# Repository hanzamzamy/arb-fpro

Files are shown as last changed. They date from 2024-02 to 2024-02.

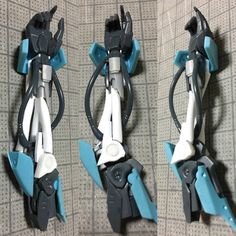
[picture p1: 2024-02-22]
Mechanical/Macrobot_Silvia Nur Aziza_Mechanical/07cd2b10f6570b833456bf622130a239.jpg

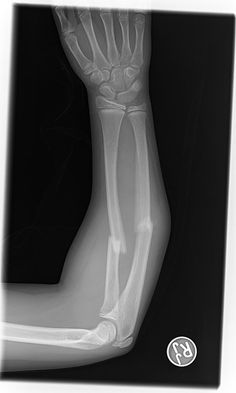
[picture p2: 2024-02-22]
Mechanical/Macrobot_Silvia Nur Aziza_Mechanical/10383fedec357cac335563712656db4f.jpg

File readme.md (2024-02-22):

# ARb Project
## Introduction
ARb is a robotic arm with 4 degrees of freedom. It is designed to be used in a variety of applications, including pick and place, etc. The arm is controlled by a host computer, which communicates with an STM32 to control the servos using UART via USB. The arm is also equipped with a sensor and a gripper, which can be used to pick up and manipulate objects. The arm is designed to be easy to use. The arm also designed to be affordable, with a total cost of less than Rp500.000,00. _Although we spent more because of trial and error, and we also bought some parts in a higher price than the market price._
## Features
- 4 degrees of freedom
- 1 gripper with integrated sensor
- Automatic find and pick up object
- Easy to use
- Fully programmable
## Components
- 3x MG996R Servo
- 2x MG90S Servo
- 1x VL53L0X Sensor
- 1x STM32F401CCU6
- 1x LM2596 DC-DC Step Down
- Custom PCB and Acrylic parts
## Tech Stack
- C -> STM32
    - HAL -> Hardware Abstraction Layer
    - VL53L0X -> Sensor
    - USB CDC -> Communication
- Python -> Host Computer
  - PySerial -> Communication
  - IKPy -> Inverse Kinematics
- Solidworks -> Design
- KiCad -> PCB Design
## Expenditure
[Rincian_Anggaran.pdf](https://github.com/hanzamzamy/arb-fpro/blob/master/Rincian_Anggaran.pdf)
## Documentation
[Video Demo.mp4](https://github.com/hanzamzamy/arb-fpro/blob/master/Dokumentasi/Video%20Demo.mp4)
[Robot.jpg](https://github.com/hanzamzamy/arb-fpro/blob/master/Dokumentasi/Barang%20e.jpg)
[Photo1.jpg](https://github.com/hanzamzamy/arb-fpro/blob/master/Dokumentasi/1.jpg)
[Photo2.jpg](https://github.com/hanzamzamy/arb-fpro/blob/master/Dokumentasi/1.jpg)
## Team
- Mechanical - [Silvia Nur Aziza]()
- Electrical - [Rayhan Rizqi Zamzamy](https://github.com/hanzamzamy)
- Programming - [Nabiel Nizar Anwari](https://github.com/bielnzar)

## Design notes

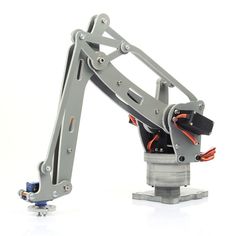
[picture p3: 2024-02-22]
Mechanical/Macrobot_Silvia Nur Aziza_Mechanical/8682ff16a06bd647c6e8e3005136eaa1.jpg

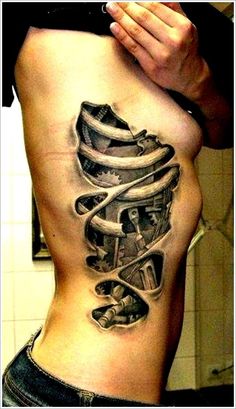
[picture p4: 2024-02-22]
Mechanical/Macrobot_Silvia Nur Aziza_Mechanical/3cdeb58c5378929b38347c03fc18d9f9.jpg

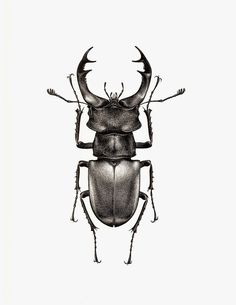
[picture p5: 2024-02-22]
Mechanical/Macrobot_Silvia Nur Aziza_Mechanical/ec5d5dfce41e124278e7852ab5f933ce.jpg

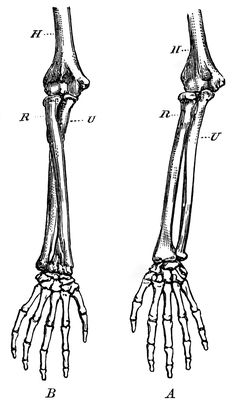
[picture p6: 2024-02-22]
Mechanical/Macrobot_Silvia Nur Aziza_Mechanical/0e78239ebd3d4895ee9c12c9efb630f2.jpg

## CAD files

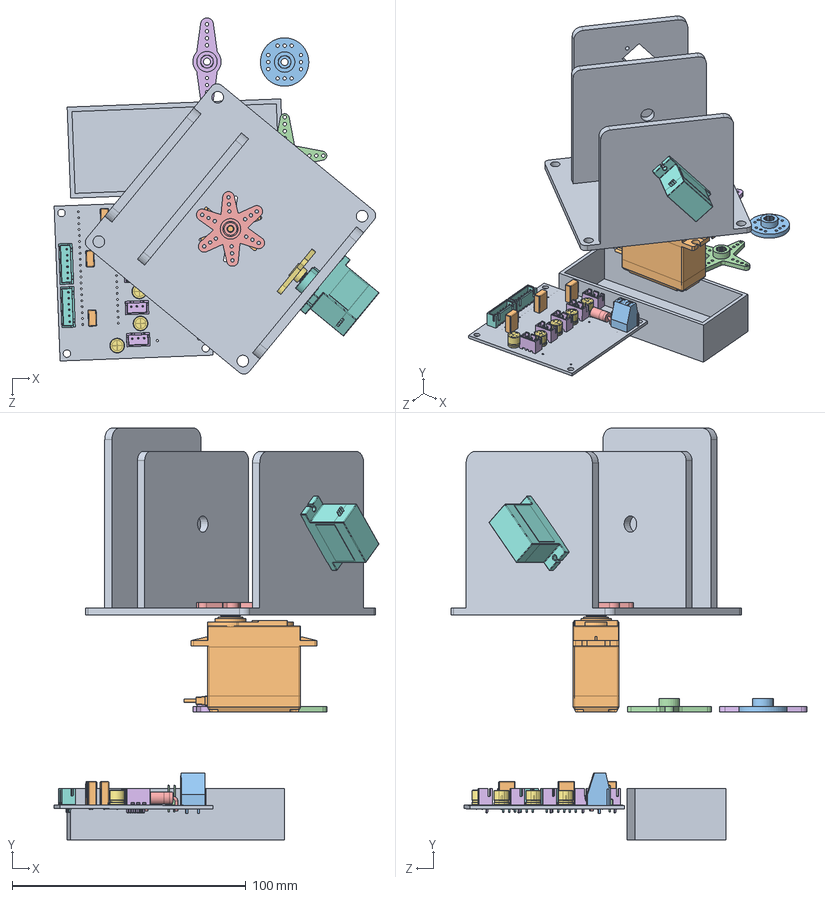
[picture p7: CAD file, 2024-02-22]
Mechanical/Macrobot_Silvia Nur Aziza_Mechanical/BASE PCB.SLDASM
138.9 x 176.2 x 152.4 mm
Robot base
servoMotorMG996R
attachmentStar
MG90servo_gear
Servo-MG90S.step
baterai
SOLID.step x 3
SOLID-0.step
SOLID-1.step
SOLID-2.step
SOLID-3.step x 5
SOLID-4.step x 5
SOLID-5.step x 2
FP_Abinara PCB.step

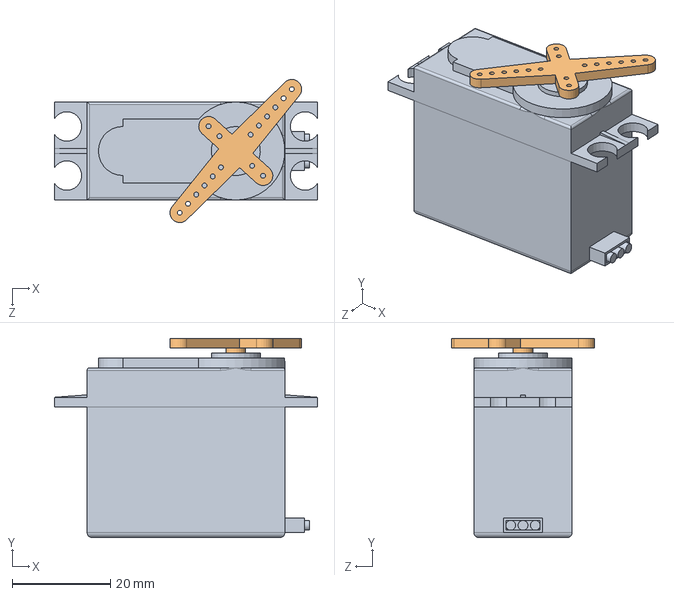
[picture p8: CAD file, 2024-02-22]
Mechanical/Macrobot_Silvia Nur Aziza_Mechanical/mg996-servo-motor-180-1.snapshot.1/Servo MG995 180/Servo MG995 Assembly.SLDASM
53.6 x 40.6 x 29.2 mm
Servo MG995
servo axe

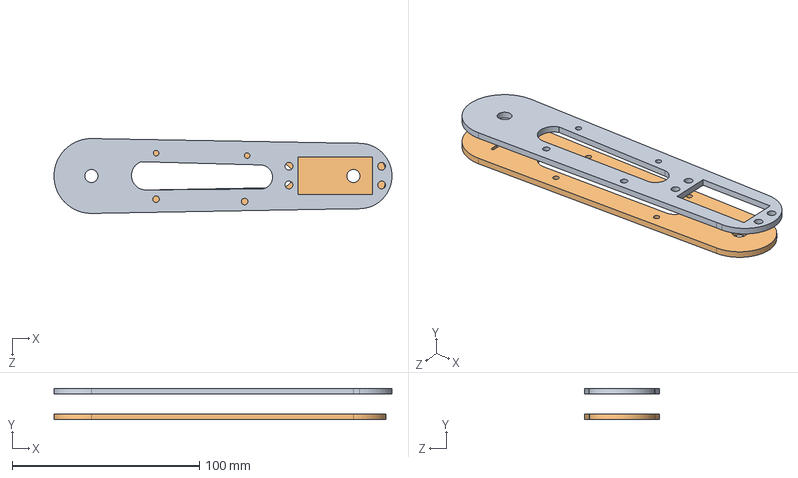
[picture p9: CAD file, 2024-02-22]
Mechanical/Macrobot_Silvia Nur Aziza_Mechanical/refisni/Assem1.SLDASM
180.6 x 16.8 x 40.0 mm
atas kanan - Copy
bawah - Copy

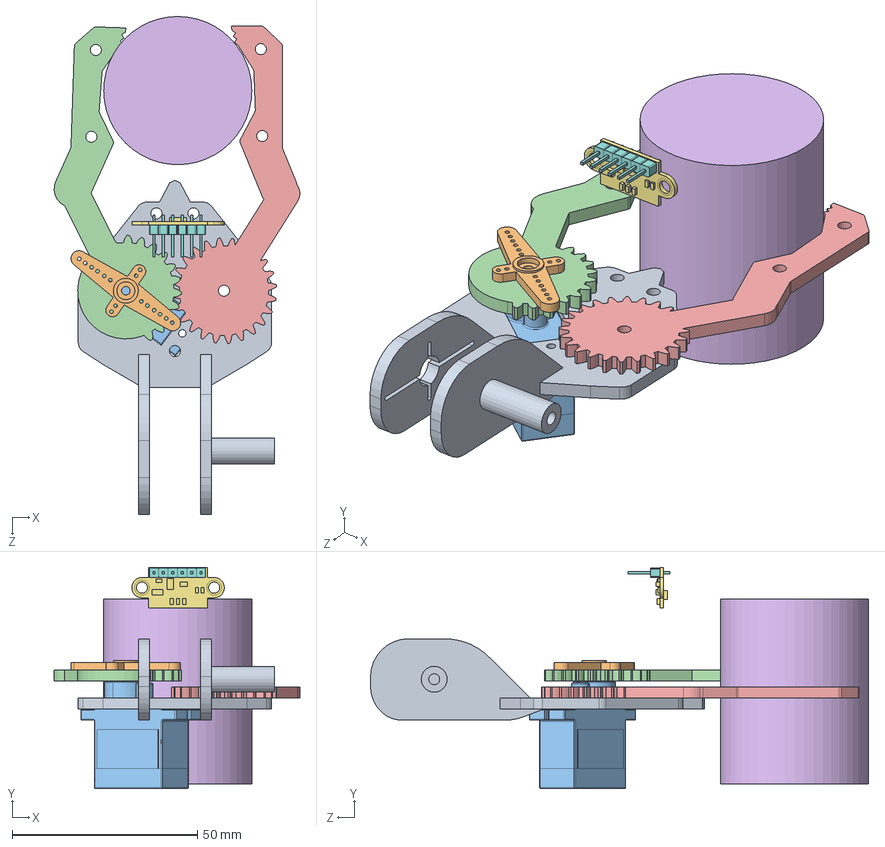
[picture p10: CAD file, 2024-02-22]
Mechanical/Macrobot_Silvia Nur Aziza_Mechanical/gripperr tolong fiksss.SLDASM
66.3 x 59.8 x 134.5 mm
tatakan griper bawah - Copy
MG90servo_gear
Gripper - Copy
capitt kanan fikss
siliner
vl53l0x_PCB.STEP
pin_header.STEP x 6

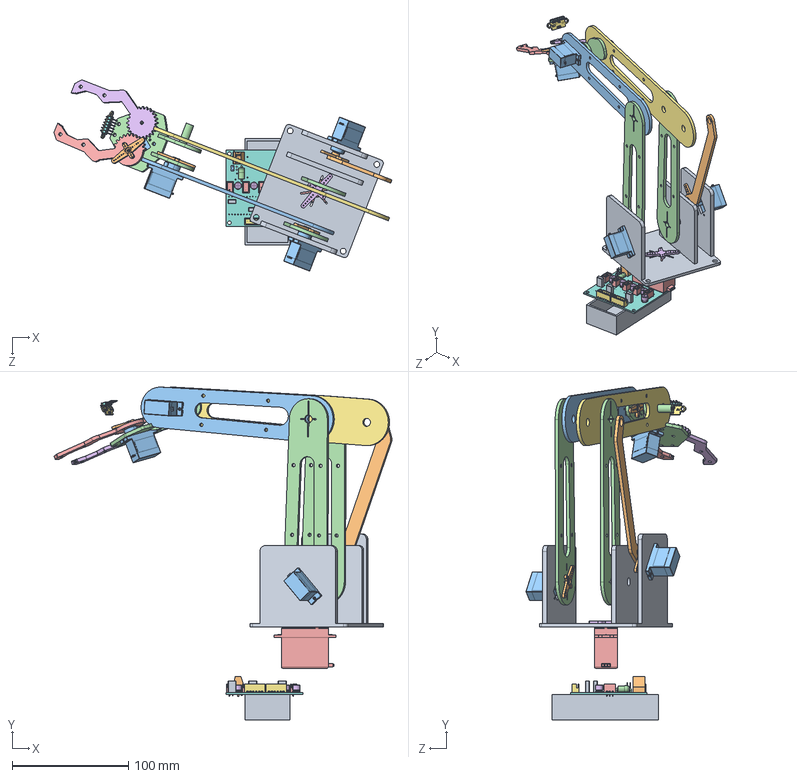
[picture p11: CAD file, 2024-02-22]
Mechanical/Macrobot_Silvia Nur Aziza_Mechanical/0totalll.SLDASM
290.9 x 286.3 x 164.5 mm
Robot base
MG90servo_gear x 4
Servo-MG90S.step x 4
tatakan griper bawah - Copy
Gripper - Copy
capitt kanan fikss
vl53l0x_PCB.STEP
pin_header.STEP x 6
SOLID.step x 3
SOLID-0.step
SOLID-1.step
SOLID-2.step
SOLID-3.step x 5
SOLID-4.step x 5
SOLID-5.step x 2
FP_Abinara PCB.step
baterai
penggerak
0atas kanan
0bawah x 2
Servo MG995
servo axe
0atas kiri pjg

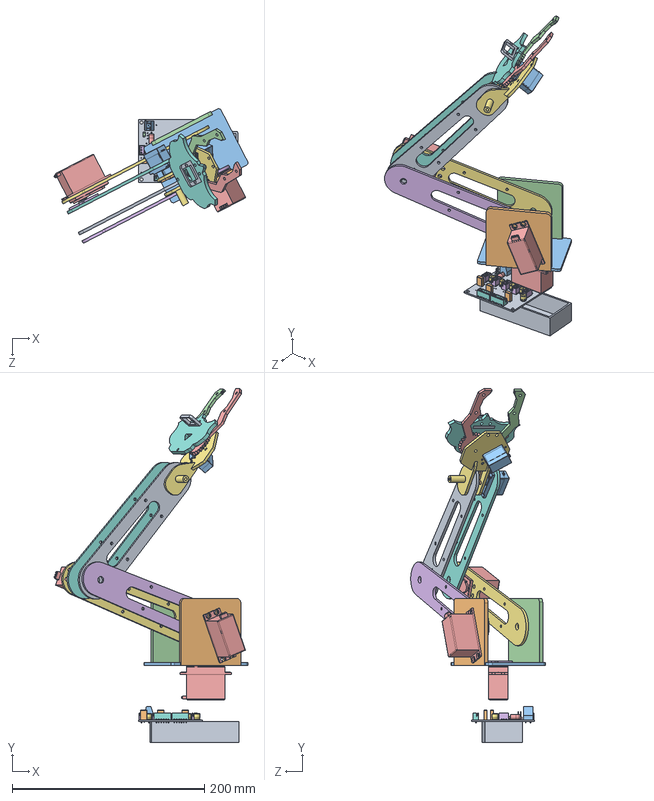
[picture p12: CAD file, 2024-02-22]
Mechanical/Macrobot_Silvia Nur Aziza_Mechanical/00total akh.SLDASM
201.8 x 368.3 x 140.1 mm
baterai
SOLID.step x 3
SOLID-0.step
SOLID-1.step
SOLID-2.step
SOLID-3.step x 5
SOLID-4.step x 5
SOLID-5.step x 2
FP_Abinara PCB.step
db 2 - Copy
revisi base
db 1
Servo MG995 x 3
servo axe x 3
tatakan griper bawah - Copy
kepala bolong
monting
MG90servo_gear x 2
Servo-MG90S.step x 2
Gripper - Copy
griper kanan fiks
bawah - Copy
atas kanan - Copy
0atas kanan
0bawah

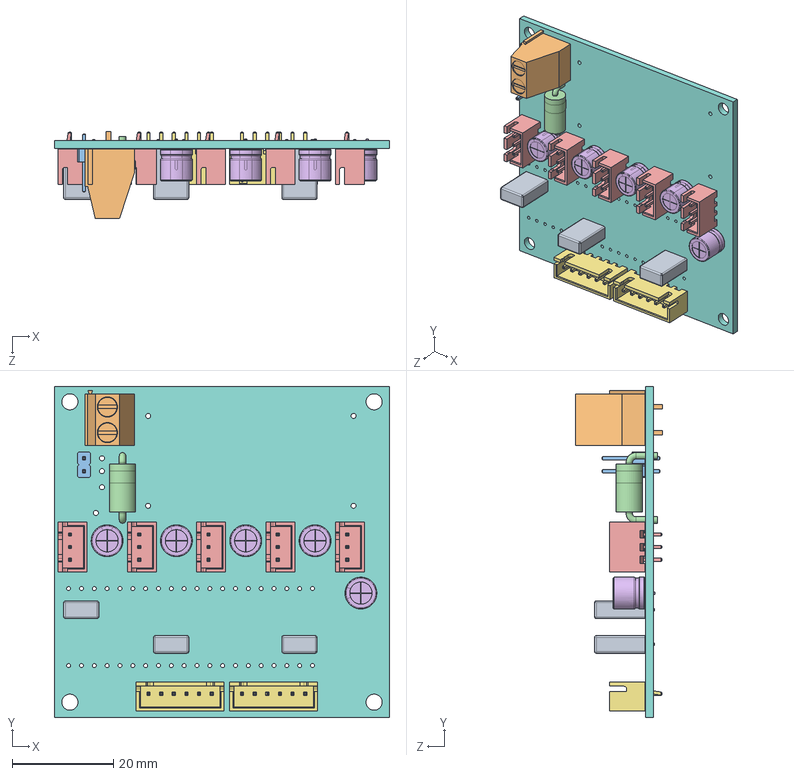
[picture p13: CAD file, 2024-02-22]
Mechanical/Macrobot_Silvia Nur Aziza_Mechanical/FP_Abinara.SLDASM
66.3 x 65.5 x 17.3 mm
SOLID.step x 3
SOLID-0.step
SOLID-1.step
SOLID-2.step
SOLID-3.step x 5
SOLID-4.step x 5
SOLID-5.step x 2
FP_Abinara PCB.step

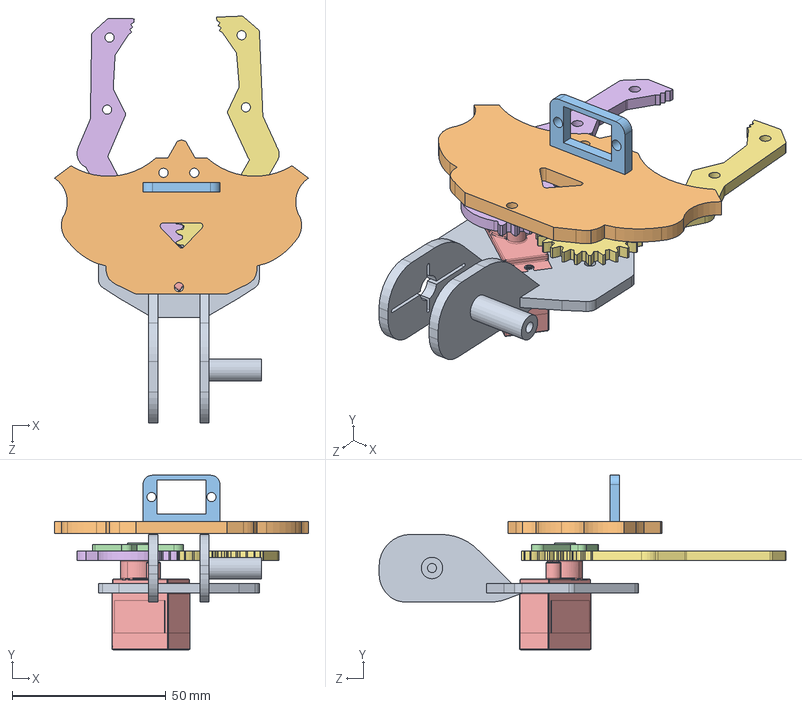
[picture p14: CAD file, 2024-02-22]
Mechanical/Macrobot_Silvia Nur Aziza_Mechanical/gfdgf.SLDASM
82.6 x 56.7 x 132.2 mm
tatakan griper bawah - Copy
kepala bolong
monting
MG90servo_gear
Servo-MG90S.step
Gripper - Copy
griper kanan fiks

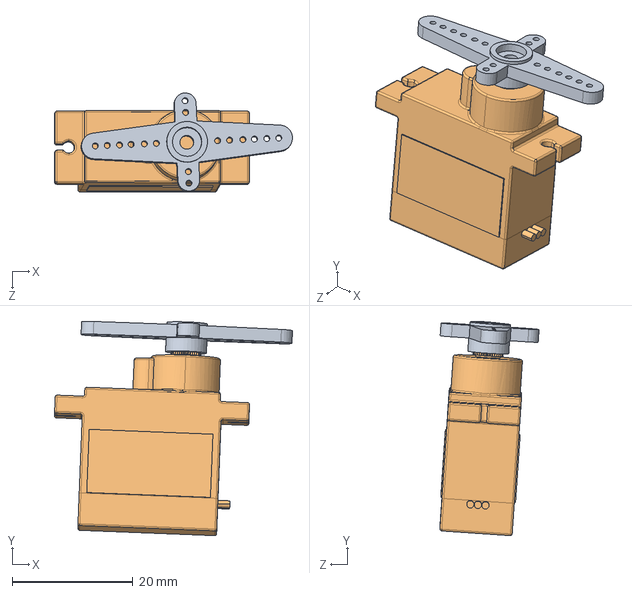
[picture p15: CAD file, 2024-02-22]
Mechanical/Macrobot_Silvia Nur Aziza_Mechanical/MG90S DENGAN BALING BALINGGG.SLDASM
39.4 x 35.5 x 16.4 mm
MG90servo_gear
Servo-MG90S.step

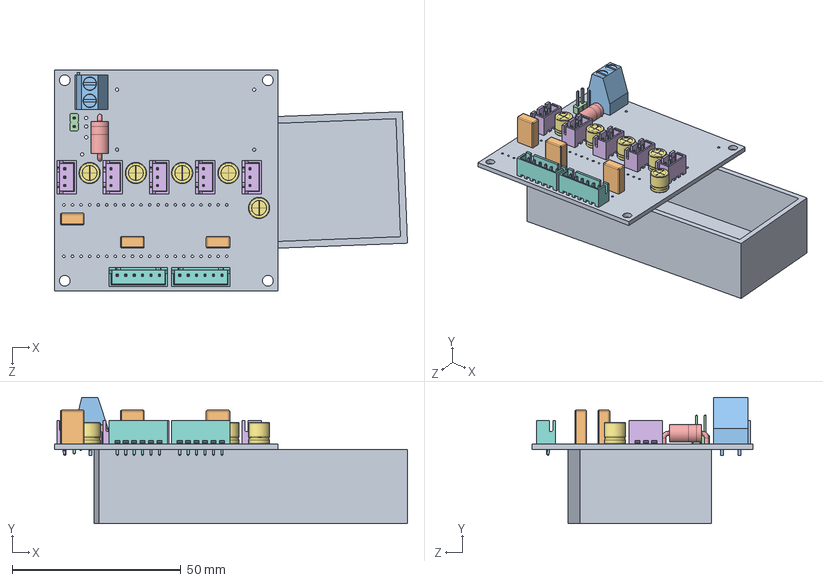
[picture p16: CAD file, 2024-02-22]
Mechanical/Macrobot_Silvia Nur Aziza_Mechanical/BAS SER966 PENOP.SLDASM
104.6 x 37.5 x 65.5 mm
baterai
SOLID.step x 3
SOLID-0.step
SOLID-1.step
SOLID-2.step
SOLID-3.step x 5
SOLID-4.step x 5
SOLID-5.step x 2
FP_Abinara PCB.step

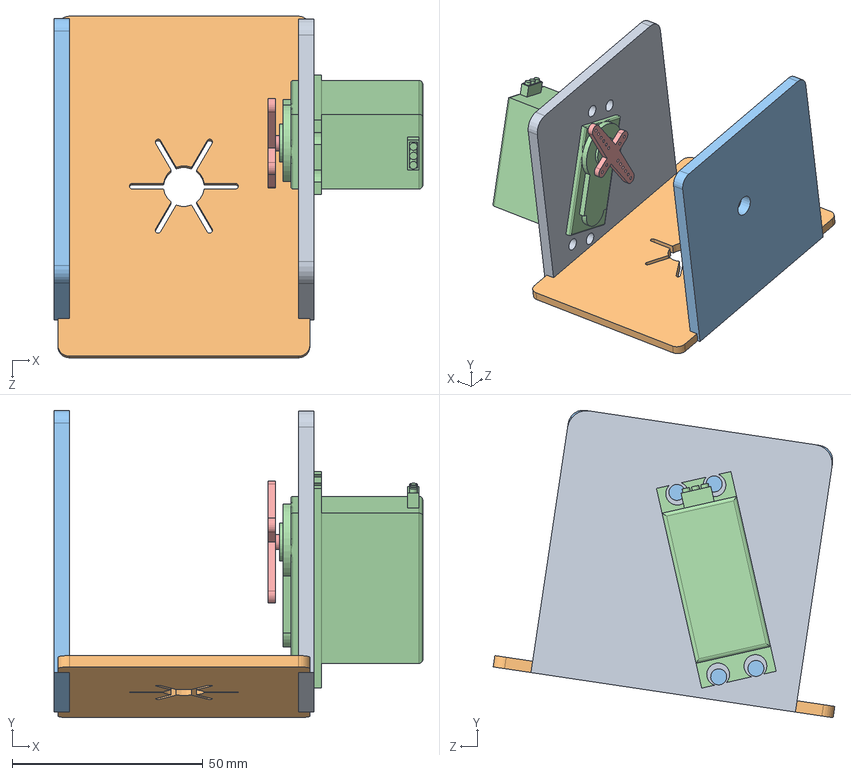
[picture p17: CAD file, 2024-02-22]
Mechanical/Macrobot_Silvia Nur Aziza_Mechanical/base putar.SLDASM
96.6 x 80.5 x 89.5 mm
db 2 - Copy
revisi base
db 1
Servo MG995
servo axe

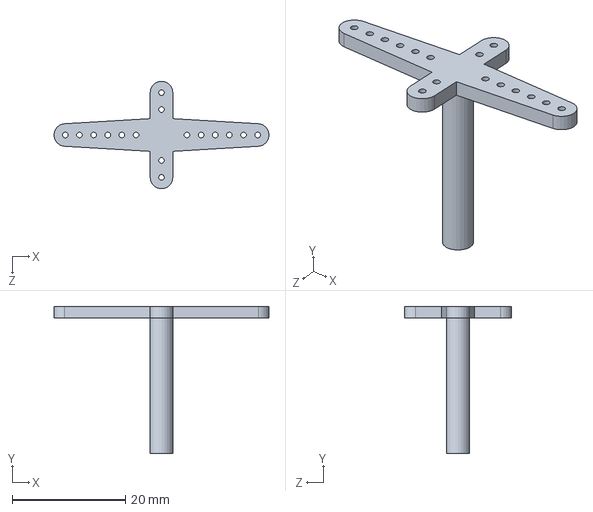
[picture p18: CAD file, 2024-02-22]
Mechanical/Macrobot_Silvia Nur Aziza_Mechanical/mg996-servo-motor-180-1.snapshot.1/Servo MG995 180/servo axe.SLDPRT
38.0 x 26.0 x 19.0 mm

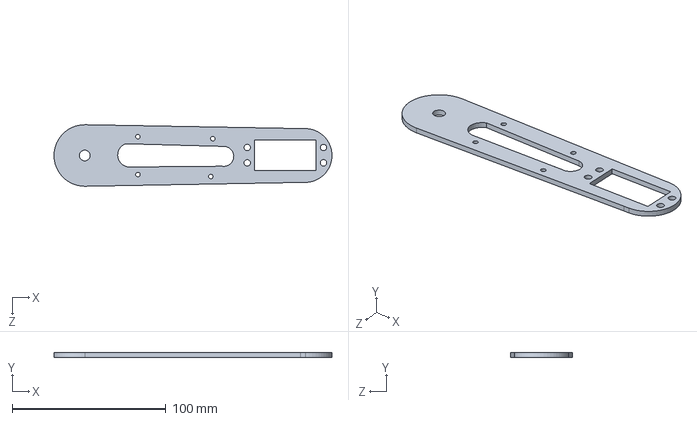
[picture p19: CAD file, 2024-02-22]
Mechanical/Macrobot_Silvia Nur Aziza_Mechanical/refisni/atas kanan - Copy.SLDPRT
180.6 x 3.00 x 40.0 mm

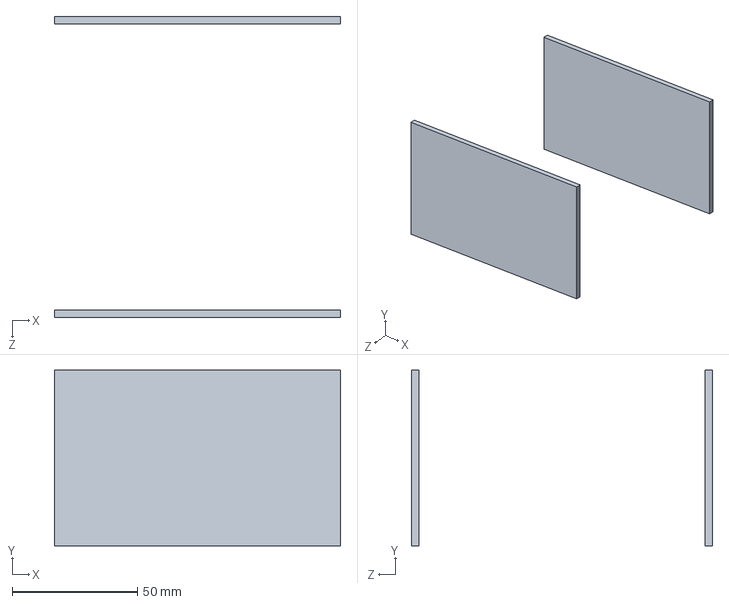
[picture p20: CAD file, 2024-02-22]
Mechanical/Macrobot_Silvia Nur Aziza_Mechanical/bs 4 lawan lubang depan blkg.SLDPRT
114.0 x 70.0 x 120.0 mm

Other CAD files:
Mechanical/Macrobot_Silvia Nur Aziza_Mechanical/SERVO MG966 UDAH SAMA BALING2SLDASM.SLDASM
Electrical/FP_Abinara/FP_Abinara.step
Mechanical/Macrobot_Silvia Nur Aziza_Mechanical/mg996-servo-motor-180-1.snapshot.1/Servo MG995 180/Servo MG995.SLDPRT
Mechanical/Macrobot_Silvia Nur Aziza_Mechanical/0 bs 1.SLDPRT
Mechanical/Macrobot_Silvia Nur Aziza_Mechanical/0atas kanan.SLDPRT
Mechanical/Macrobot_Silvia Nur Aziza_Mechanical/0atas kiri pjg.SLDPRT
Mechanical/Macrobot_Silvia Nur Aziza_Mechanical/0bawah.SLDPRT
Mechanical/Macrobot_Silvia Nur Aziza_Mechanical/FP23_Object.SLDPRT
Mechanical/Macrobot_Silvia Nur Aziza_Mechanical/Gripper - Copy.SLDPRT
Mechanical/Macrobot_Silvia Nur Aziza_Mechanical/Robot base.SLDPRT
Mechanical/Macrobot_Silvia Nur Aziza_Mechanical/SIlvia Nur Aziza_cetak akrilik.DWG
Mechanical/Macrobot_Silvia Nur Aziza_Mechanical/Silvia Nur Aiza_cetak akrilik.DWG
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

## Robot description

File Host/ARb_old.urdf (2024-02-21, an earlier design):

<robot name="Arb">

  <!-- Fix Link -->
  <link name="base_link">
    <visual>
      <origin xyz="0 0 0.0375" rpy="0 0 0"/>
      <geometry>
        <cylinder length="0.075" radius="0.01"/>
      </geometry>
    </visual>
  </link>

  <!-- Link 1 -->
  <link name="link1">
    <visual>
      <origin xyz="0 0 0.0225" rpy="0 0 0"/>
      <geometry>
        <cylinder length="0.045" radius="0.01"/>
      </geometry>
    </visual>
  </link>

  <!-- Joint 1 -->
  <joint name="joint1" type="revolute">
    <parent link="base_link"/>
    <child link="link1"/>
    <axis xyz="0 0 1"/>
    <origin xyz="0 0 0.075" rpy="0 0 -1.570796"/>
<limit effort="1000.0" lower="0" upper="3.141593" velocity="0.001"/>
  </joint>

  <!-- Link 2 -->
  <link name="link2">
    <visual>
      <origin xyz="0 0 0.07" rpy="0 0 0"/>
      <geometry>
        <cylinder length="0.14" radius="0.01"/>
      </geometry>
    </visual>
  </link>

  <!-- Joint 2 -->
  <joint name="joint2" type="revolute">
    <parent link="link1"/>
    <child link="link2"/>
    <axis xyz="1 0 0"/>
    <origin xyz="0 0 0.045" rpy="-1.570796 0 0"/>
<limit effort="1000.0" lower="0" upper="3.141593" velocity="0.001"/>
  </joint>

  <!-- Link 3 -->
  <link name="link3">
    <visual>
      <origin xyz="0 0 0.07" rpy="0 0 0"/>
      <geometry>
        <cylinder length="0.14" radius="0.01"/>
      </geometry>
    </visual>
  </link>

  <!-- Joint 3 -->
  <joint name="joint3" type="revolute">
    <parent link="link2"/>
    <child link="link3"/>
    <axis xyz="1 0 0"/>
    <origin xyz="0 0 0.14" rpy="-1.570796 0 0"/>
<limit effort="1000.0" lower="0" upper="3.141593" velocity="0.001"/>
  </joint>

  <!-- Link 4 -->
  <link name="link4">
    <visual>
      <origin xyz="0 0 0.04" rpy="0 0 0"/>
      <geometry>
        <cylinder length="0.08" radius="0.01"/>
      </geometry>
    </visual>
  </link>

  <!-- Joint 4 -->
  <joint name="joint4" type="revolute">
    <parent link="link3"/>
    <child link="link4"/>
    <axis xyz="1 0 0"/>
    <origin xyz="0 0 0.14" rpy="-1.570796 0 0"/>
<limit effort="1000.0" lower="0" upper="3.141593" velocity="0.001"/>
  </joint>

  <!-- Gripper -->
  <link name="gripper">
    <visual>
      <origin xyz="0 0 0" rpy="0 0 0"/>
      <geometry>
        <cylinder length="0" radius="0.01"/>
      </geometry>
    </visual>
  </link>

<!-- End-Effector
  <joint name="endeff" type="revolute">
    <parent link="link4"/>
<child link="gripper"/>
    <axis xyz="1 0 0"/>
    <origin xyz="0 0 0.08" rpy="-1.570796 0 0"/>
<limit effort="1000.0" lower="0" upper="3.141593" velocity="0.001"/>
  </joint>
-->
</robot>

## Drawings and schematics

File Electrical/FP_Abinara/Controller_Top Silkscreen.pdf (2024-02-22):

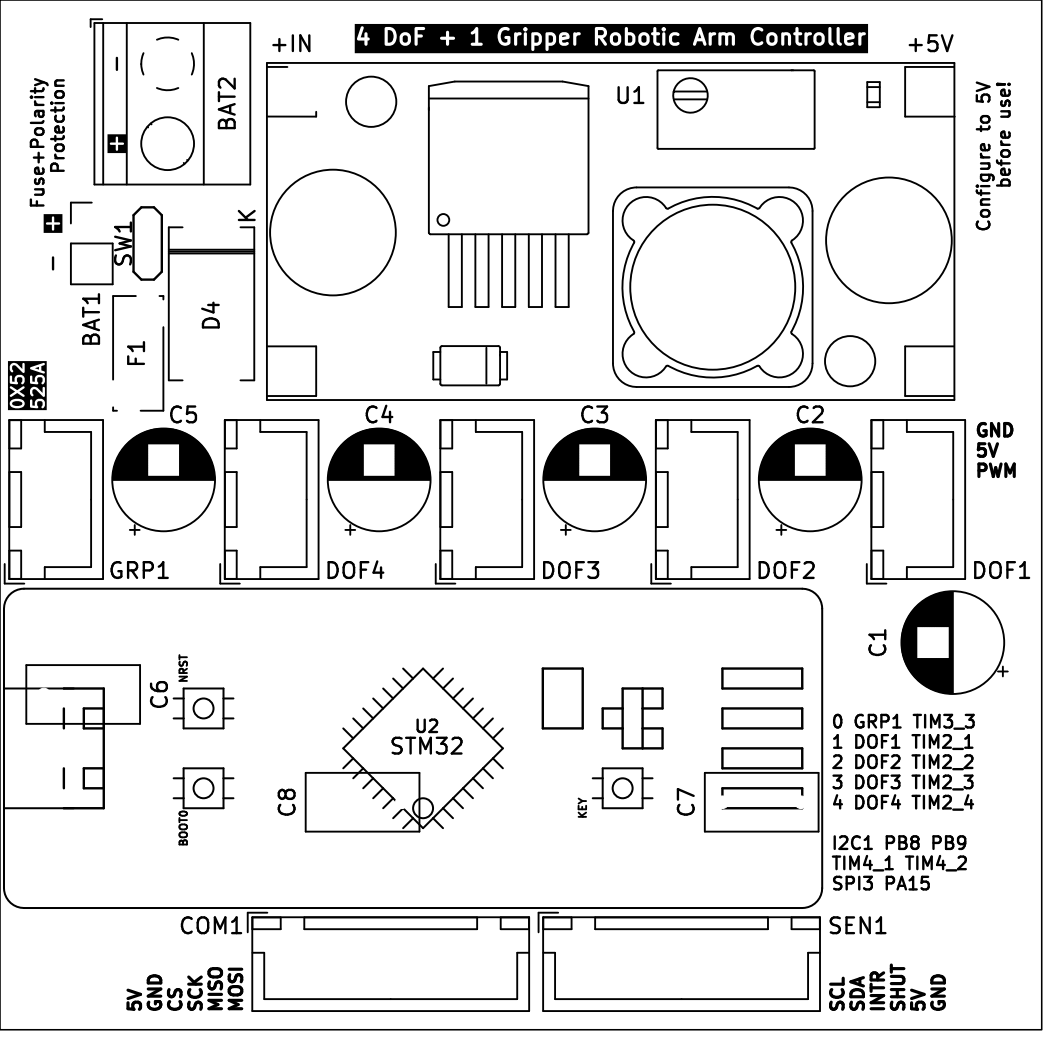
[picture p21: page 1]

- Fuse+Polarity Protection Configure to 5V before use! 0 GRP1 TIM3_3

- 5VGND CSSCK MISO MOSI SW1 C7 BAT2 BAT1 C6 D4 K GRP1 U1 C2 C8 C5 C3 DOF4 C1 F1 U2 BOOT0 STM32 NRST KEY SEN1 DOF3 DOF2 DOF1 COM1 C4

GND
PWM SCL SDA INTR SHUT 5VGND

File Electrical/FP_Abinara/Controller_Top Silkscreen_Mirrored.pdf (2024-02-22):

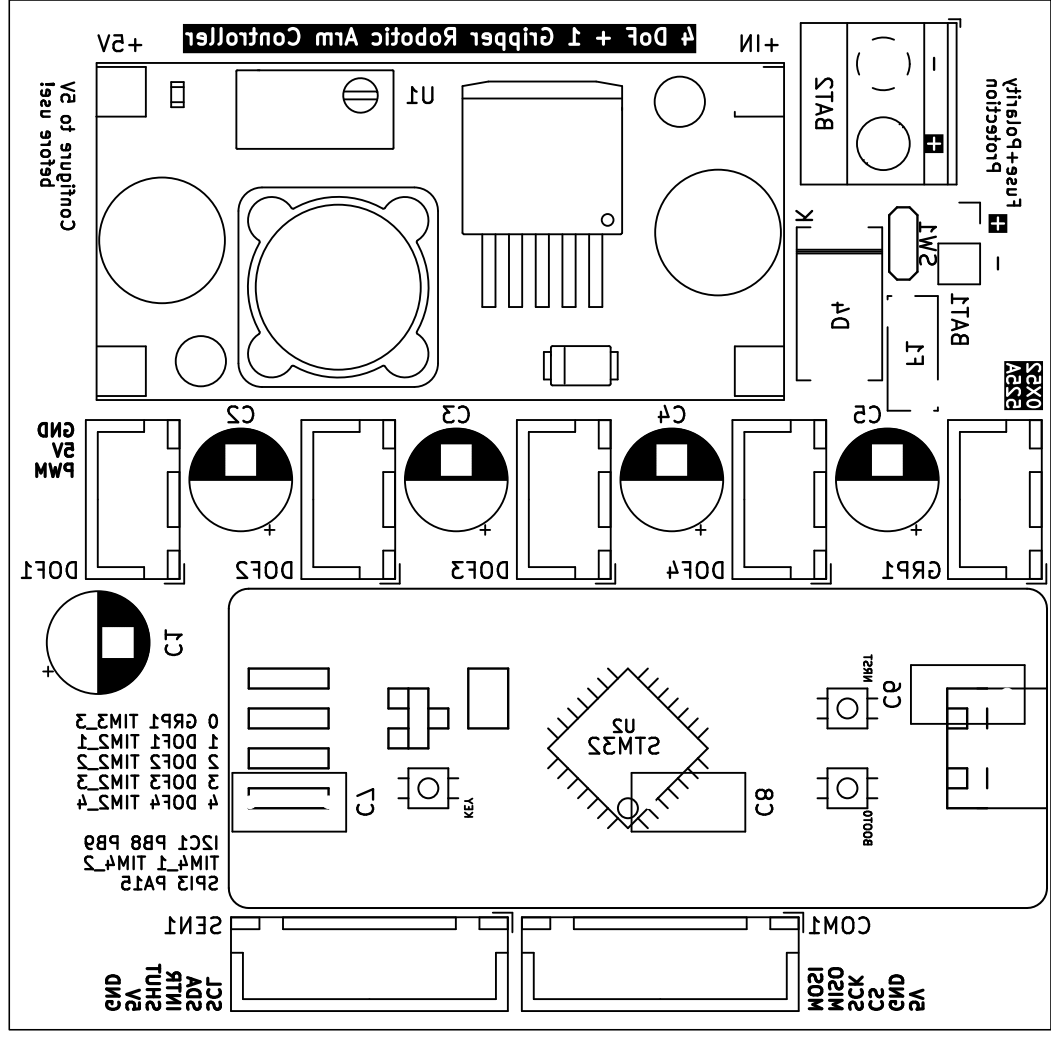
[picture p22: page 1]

- Fuse+Polarity Protection Configure to 5V before use! TIM3_3 GRP1 0 TIM2_1 DOF1 1 TIM2_2 DOF2 2 TIM2_3 DOF3 3 TIM2_4 DOF4 4 PB9 PB8 I2C1 TIM4_2 TIM4_1PA15 SPI3 +5V +IN

- MOSI MISO SCK CSGND 5V SW1 C7 BAT2 BAT1 C6 D4 K GRP1 U1 C2 C8 C3 C5 DOF4 C1 F1 U2 BOOT0 STM32 NRST KEY SEN1 DOF1 DOF2 DOF3 COM1 C4

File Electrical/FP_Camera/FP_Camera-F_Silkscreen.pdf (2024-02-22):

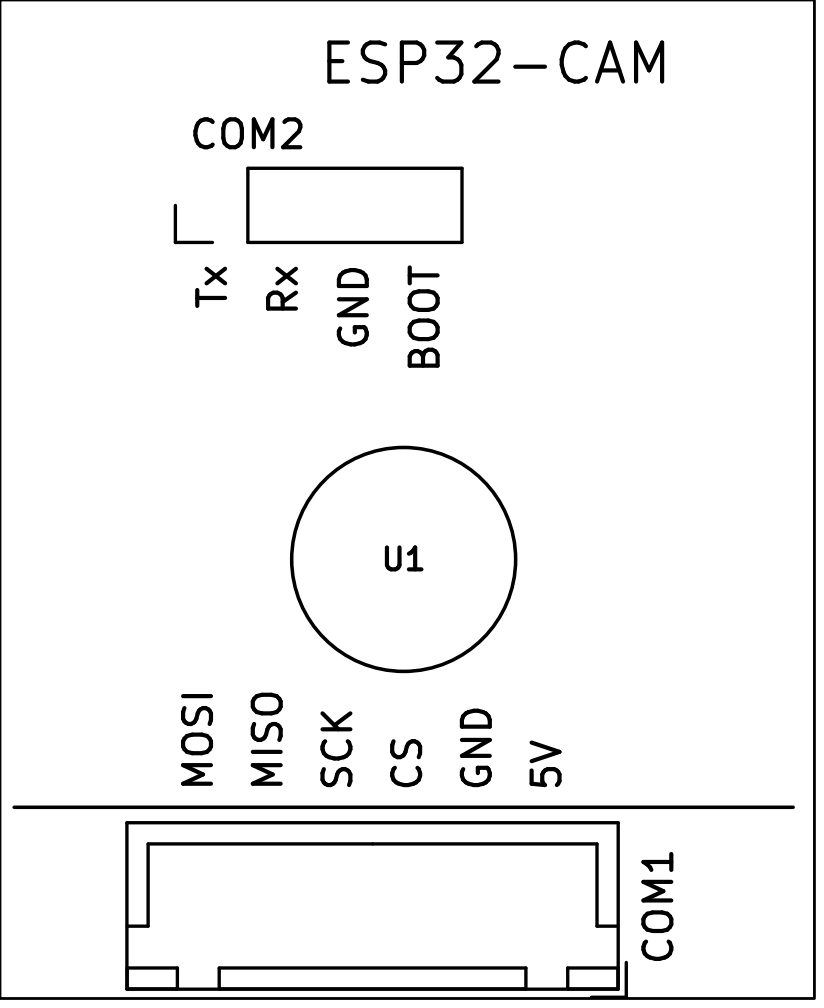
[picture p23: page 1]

MOSI MISO SCK CSGND 5V GND BOOTTx Rx U1 ESP32-CAM

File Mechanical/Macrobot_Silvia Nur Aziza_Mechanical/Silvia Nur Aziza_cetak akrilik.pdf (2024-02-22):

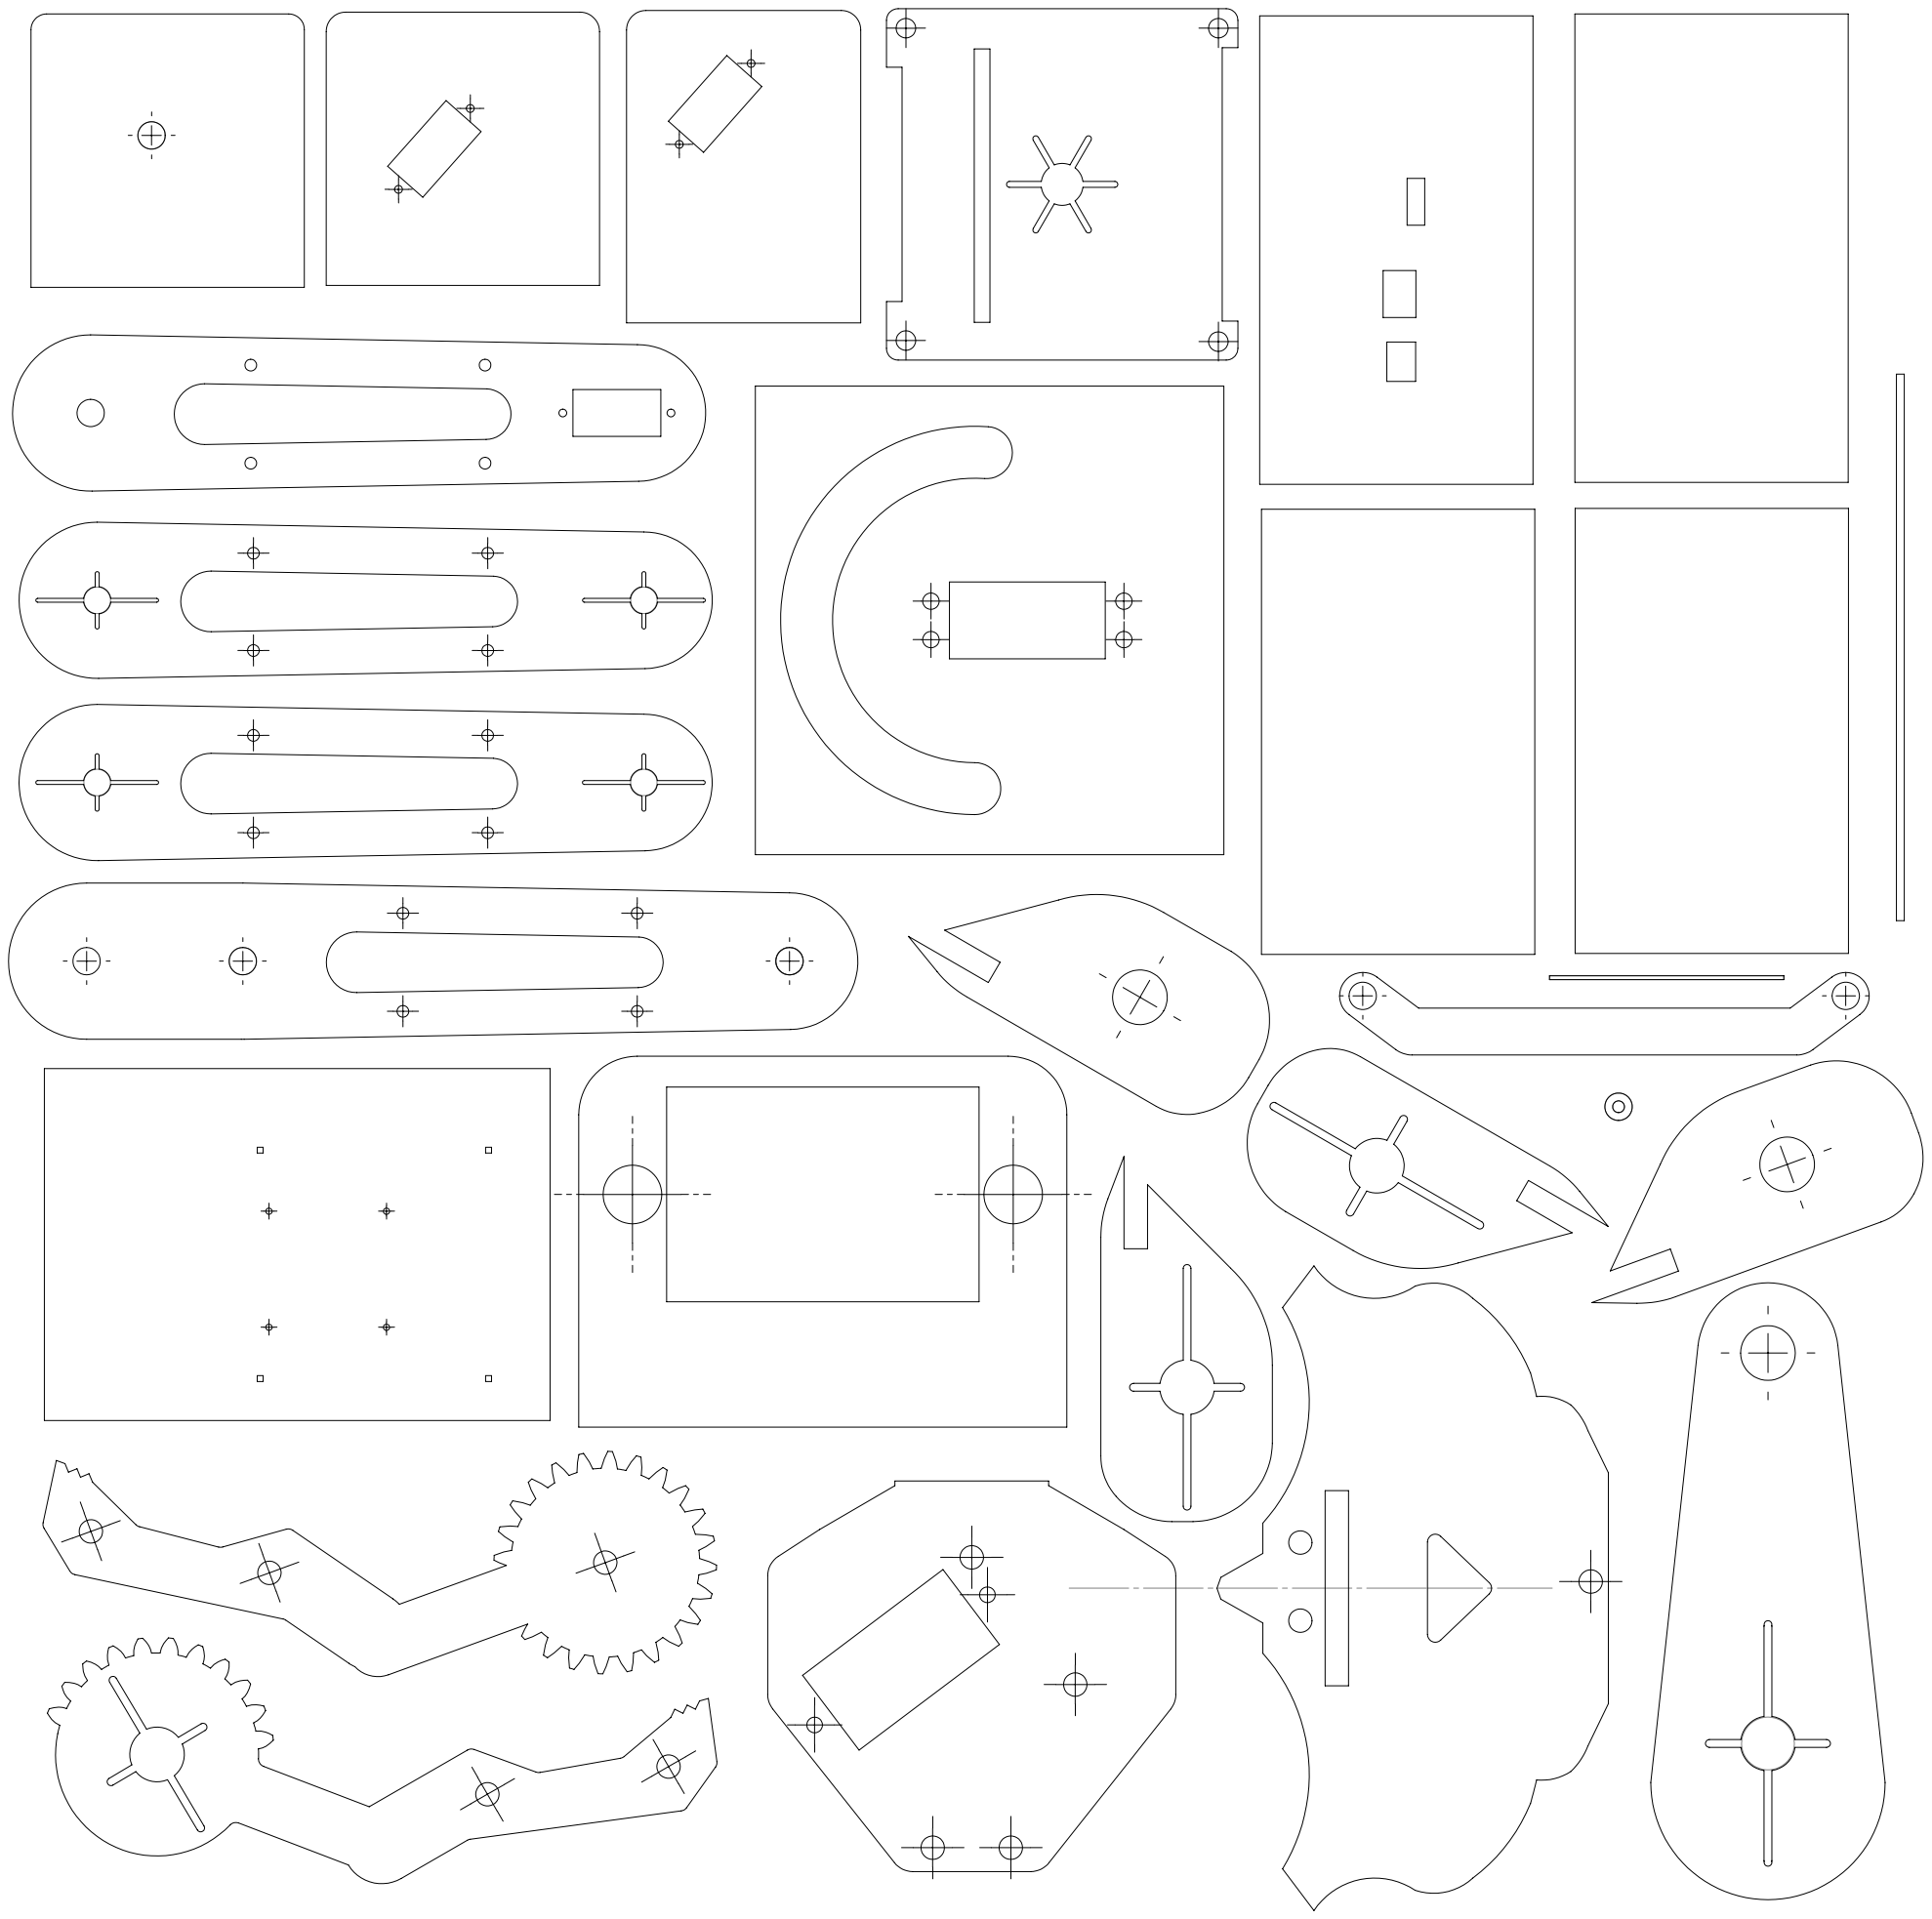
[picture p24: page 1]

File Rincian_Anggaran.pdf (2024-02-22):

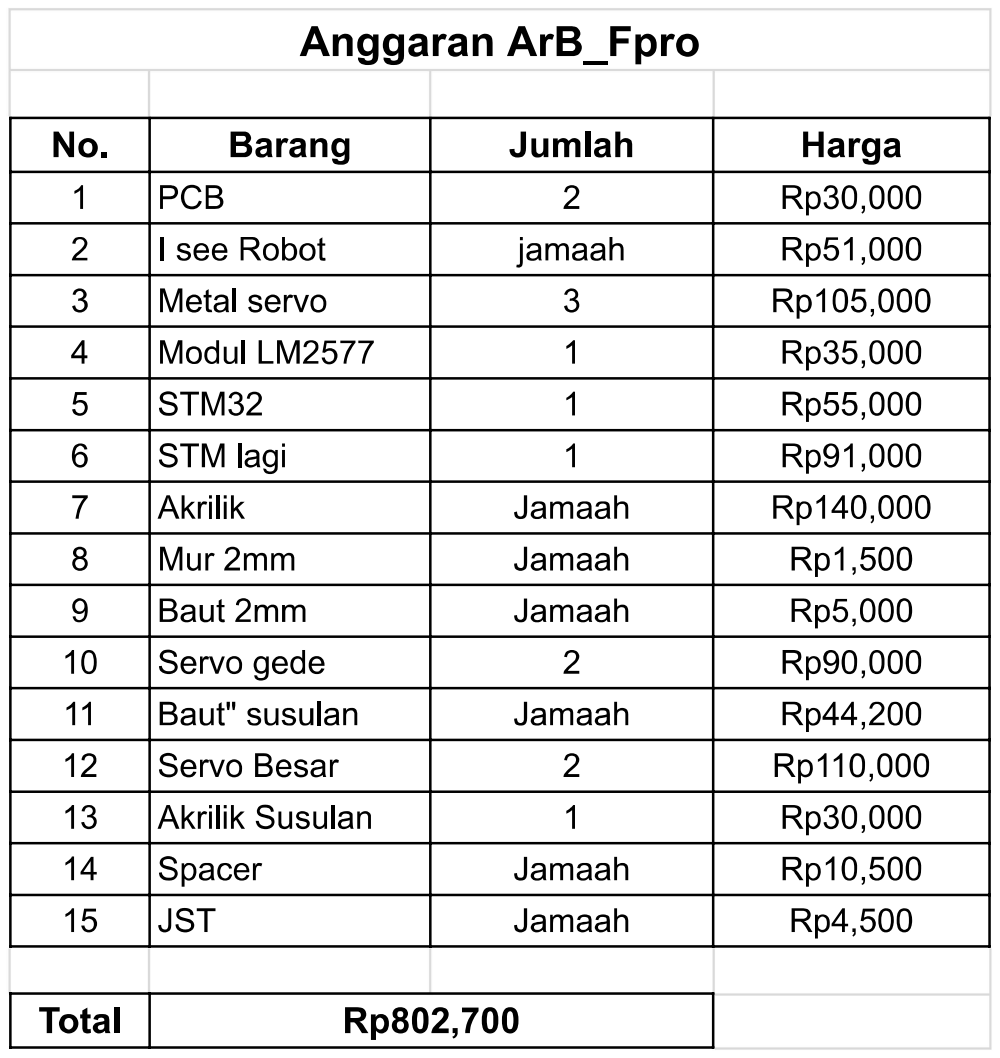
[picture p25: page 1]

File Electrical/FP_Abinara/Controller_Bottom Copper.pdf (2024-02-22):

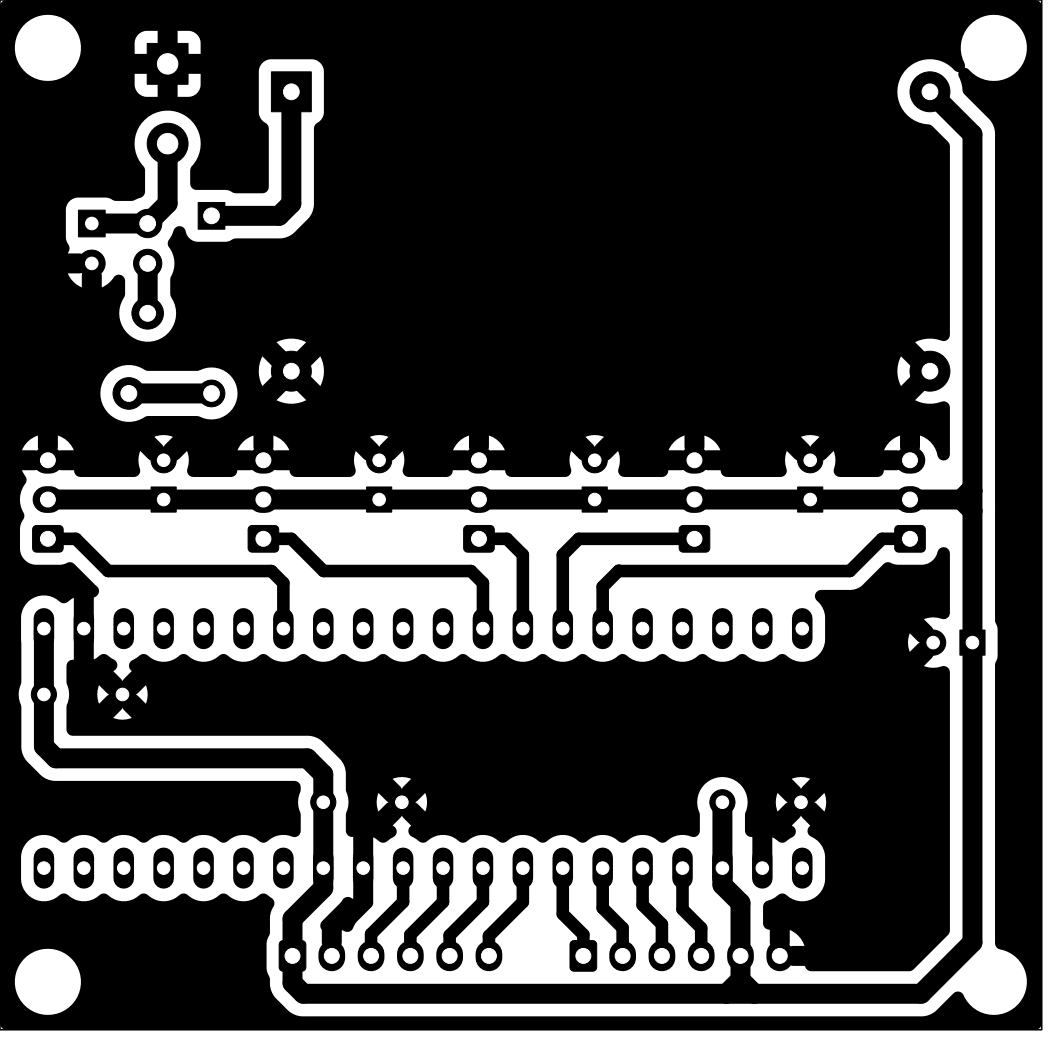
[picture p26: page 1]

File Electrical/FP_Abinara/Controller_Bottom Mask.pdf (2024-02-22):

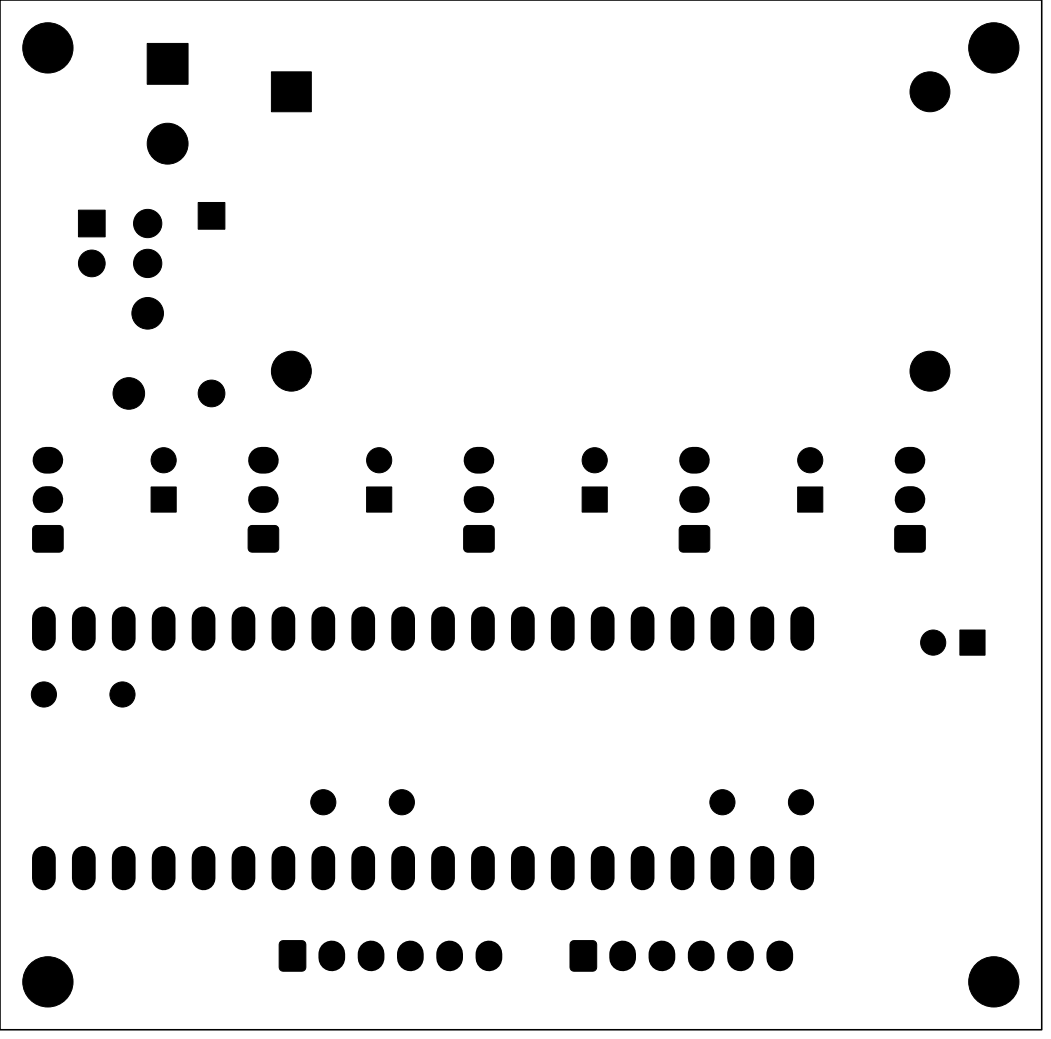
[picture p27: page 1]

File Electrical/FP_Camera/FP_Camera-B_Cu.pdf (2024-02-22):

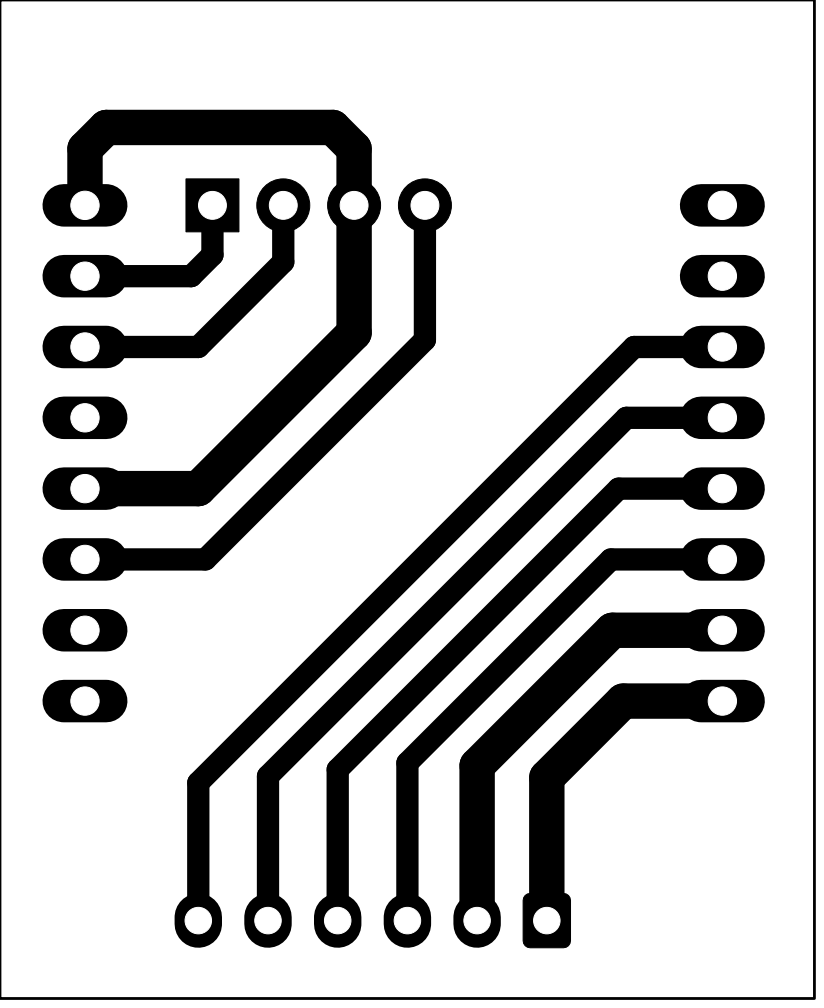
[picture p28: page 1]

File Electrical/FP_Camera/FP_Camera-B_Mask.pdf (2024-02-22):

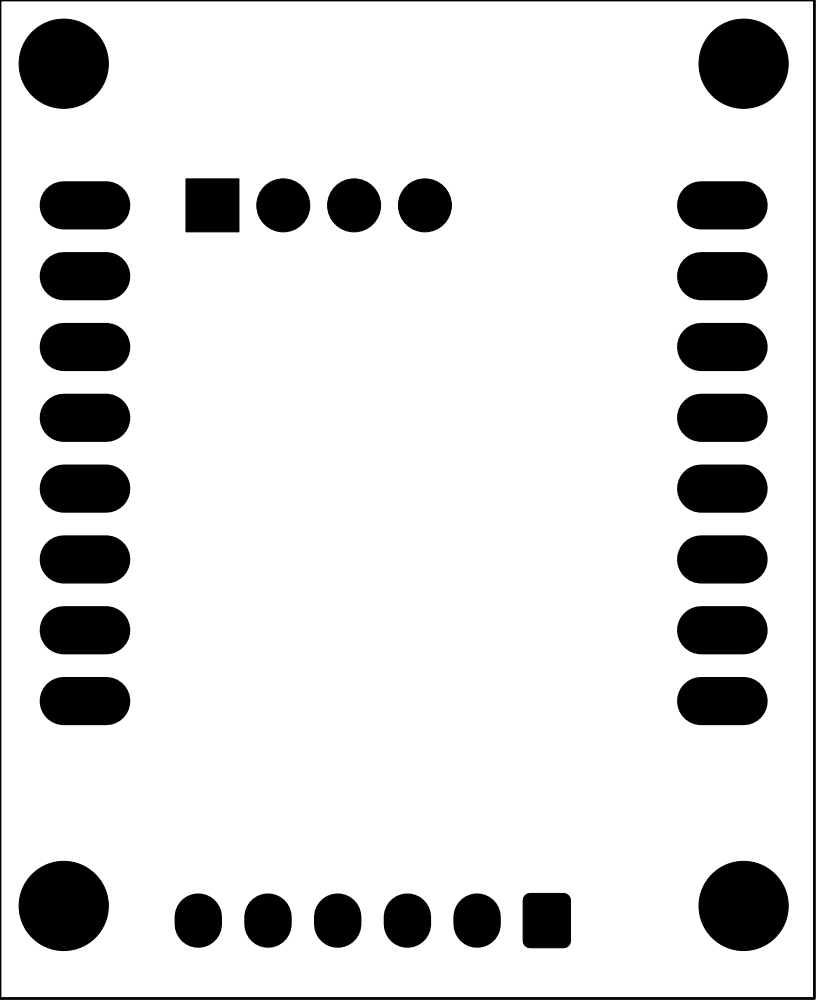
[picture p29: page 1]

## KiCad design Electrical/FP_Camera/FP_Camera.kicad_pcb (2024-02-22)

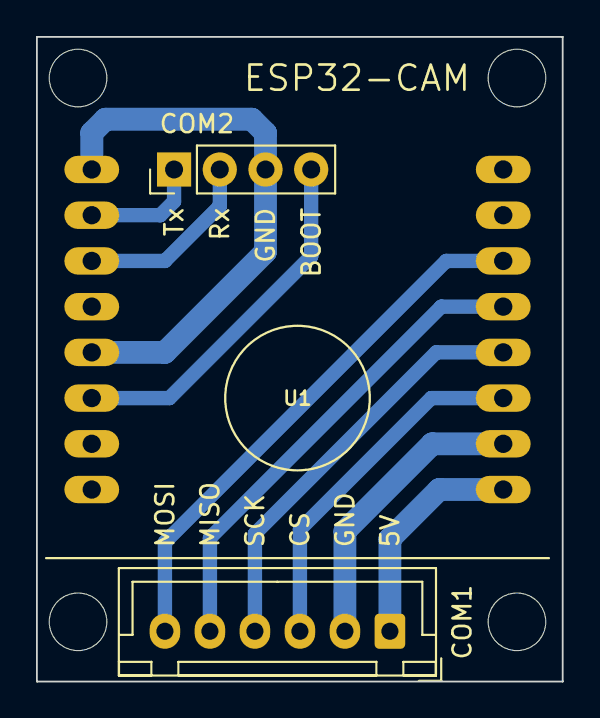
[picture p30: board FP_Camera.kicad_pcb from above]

Board: 2 copper layers, 29.2 x 35.8 mm, 3 parts (0 on the bottom side), 9 nets.

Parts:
COM1: STM32; JST_XH_B6B-XH-A_1x06_P2.50mm_Vertical
COM2: USB-TTL; PinHeader_1x04_P2.54mm_Vertical
U1: ESP32-CAM

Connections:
+5V: COM1.1, U1.P$9 (5V)
BOOT: COM2.4, U1.P$6 (GPIO0)
CSEL: COM1.3, U1.P$11 (GPIO12)
GND: COM1.2, COM2.3, U1.P$1 (GND@1), U1.P$5 (GND@2), U1.P$10 (GND@3)
MISO: COM1.5, U1.P$13 (GPIO15)
MOSI: COM1.6, U1.P$14 (GPIO14)
RX: COM2.2, U1.P$3 (GPIO3)
SCLK: COM1.4, U1.P$12 (GPIO13)
TX: COM2.1, U1.P$2 (GPIO1)

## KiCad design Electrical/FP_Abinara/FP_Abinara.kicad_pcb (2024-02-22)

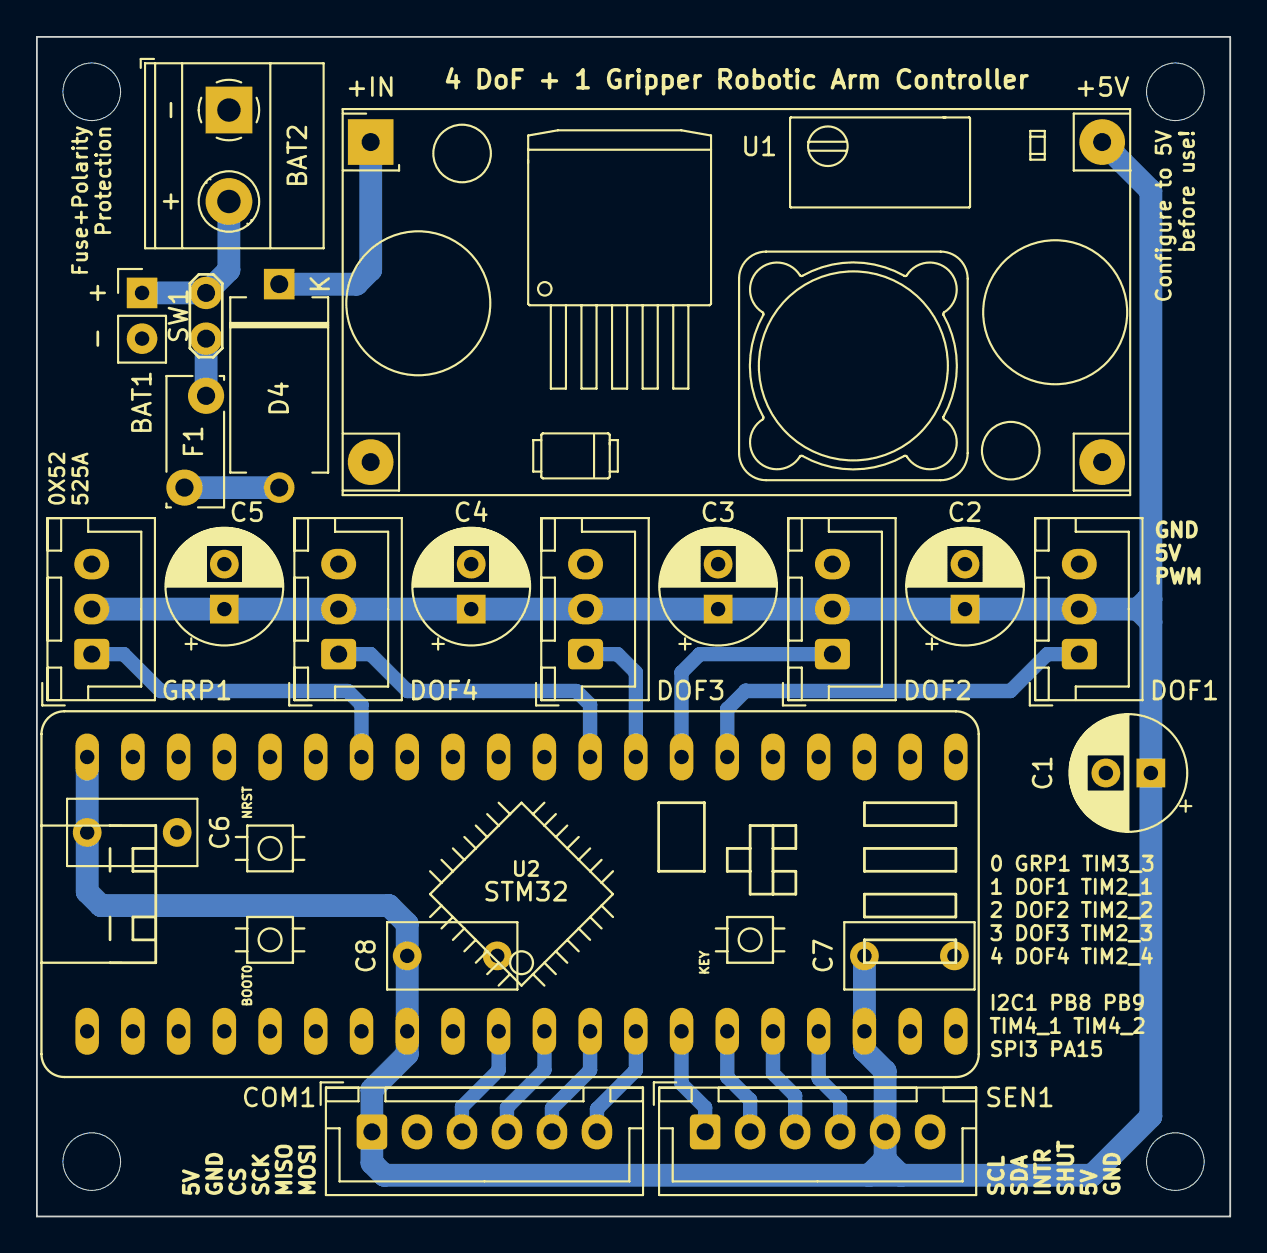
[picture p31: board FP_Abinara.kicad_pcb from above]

Board: 2 copper layers, 66.3 x 65.5 mm, 22 parts (0 on the bottom side), 19 nets.

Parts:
BAT1: JST-RE; PinHeader_1x02_P2.54mm_Vertical
BAT2: Terminal Block; TerminalBlock_Phoenix_MKDS-1,5-2-5.08_1x02_P5.08mm_Horizont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
C1, C2, C3, C4, C5: 220u; CP_Radial_D6.3mm_P2.50mm
C6, C7, C8: 220n; C_Rect_L7.0mm_W3.5mm_P5.00mm
COM1: ESP32-CAM; JST_XH_B6B-XH-A_1x06_P2.50mm_Vertical
D4: 1N5822; D_DO-201AD_P12.70mm_Horizontal
DOF1, DOF2: MG995; JST_XH_B3B-XH-A_1x03_P2.50mm_Vertical
DOF3, DOF4: MG90; JST_XH_B3B-XH-A_1x03_P2.50mm_Vertical
F1: 6A; Fuse_Bourns_MF-RG300
GRP1: MG90; JST_XH_B3B-XH-A_1x03_P2.50mm_Vertical
SEN1: VL53L0X; JST_XH_B6B-XH-A_1x06_P2.50mm_Vertical
SW1: SW_SPST; TestPoint_2Pads_Pitch2.54mm_Drill0.8mm
U1: StepDown_LM2596; YAAJ_DCDC_StepDown_LM2596
U2: BLACK_PILL

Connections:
+5V: C1.1, C2.1, C3.1, C4.1, C5.1, C6.1, C7.1, C8.1, COM1.1, DOF1.2, DOF2.2, DOF3.2, DOF4.2, GRP1.2, SEN1.5, U1.4 (Vout), U2.5V, U2.5V1, U2.PA11
+12V: BAT1.1, BAT2.2, SW1.1 (A)
CSEL: COM1.3, U2.PA15
GND: BAT1.2, BAT2.1, C1.2, C2.2, C3.2, C4.2, C5.2, C6.2, C7.2, C8.2, COM1.2, DOF1.3, DOF2.3, DOF3.3, DOF4.3, GRP1.3, SEN1.6, U1.2 (GND), U1.3 (GND), U2.GND, U2.GND1, U2.PA12
INTR: SEN1.3, U2.PB8
MISO: COM1.5, U2.PB4
MOSI: COM1.6, U2.PB5
unnamed: D4.2 (A), F1.2
unnamed: D4.1 (K), U1.1 (Vin)
unnamed: F1.1, SW1.2 (B)
PWM1: DOF1.1, U2.PA0
PWM2: DOF2.1, U2.PA1
PWM3: DOF3.1, U2.PA2
PWM4: DOF4.1, U2.PA3
PWM5: GRP1.1, U2.PB0
SCL: SEN1.1, U2.PB6
SCLK: COM1.4, U2.PB3
SDA: SEN1.2, U2.PB7
SHUT: SEN1.4, U2.PB9

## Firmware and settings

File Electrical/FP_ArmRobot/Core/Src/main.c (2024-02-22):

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
/* Includes ------------------------------------------------------------------*/
#include "main.h"
#include "usb_device.h"

/* USER CODE BEGIN Includes */
#include "servo.h"
#include "usbd_cdc_if.h"
#include "cmd_handler.h"
//#include "custom_daq.h"
#include "vl53l0x_api.h"
/* USER CODE END Includes */

/* USER CODE BEGIN PD */
#define INRANGE(x,m,M)(x > m && x < M) // Check if value in range. Not used
/* USER CODE END PD */

I2C_HandleTypeDef hi2c1;

TIM_HandleTypeDef htim2;
TIM_HandleTypeDef htim3;

/* USER CODE BEGIN PV */
Servo_t dof1, dof2, dof3, dof4, grp1; // Servos

volatile stat_t process = { 0, 0, 0, 0, 0, 0, 0, 0, 0, 0, 0, 0 }; // Flags. Some not being used (feature not implemented/tested/fail)
char rxBuff[BUFLEN], txBuff[BUFLEN]; // UART process buffer

VL53L0X_Dev_t tof; // VL53L0X device
VL53L0X_RangingMeasurementData_t rangeData; // Sensor range

/* USER CODE END PV */

void SystemClock_Config(void);
static void MX_GPIO_Init(void);
static void MX_TIM2_Init(void);
static void MX_TIM3_Init(void);
static void MX_I2C1_Init(void);
/* USER CODE BEGIN PFP */
void Sensor_Init(void);
void Actuator_Init(void);
/* USER CODE END PFP */

/* USER CODE BEGIN 0 */
void HAL_GPIO_EXTI_Callback(uint16_t GPIO_PIN) {
	process.sensor = 1; // New sample ready to process

	//Custom_DAQ();
}
/* USER CODE END 0 */

/**
 * @brief  The application entry point.
 * @retval int
 */
int main(void) {
	/* MCU Configuration--------------------------------------------------------*/

	/* Reset of all peripherals, Initializes the Flash interface and the Systick. */
	HAL_Init();

	/* Configure the system clock */
	SystemClock_Config();

	/* Initialize all configured peripherals */
	MX_GPIO_Init();
	MX_TIM2_Init();
	MX_TIM3_Init();
	MX_USB_DEVICE_Init();
	MX_I2C1_Init();
	/* USER CODE BEGIN 2 */
	HAL_Delay(1000); // Just small delay before using I2C. Fix HAL_BUSY
	Sensor_Init();
	Actuator_Init();
	/* USER CODE END 2 */

	/* Infinite loop */
	/* USER CODE BEGIN WHILE */
	while (1) {
		// Post-Sensor Interrupt Action
		if (process.sensor) {
			process.sensor = 0;
			VL53L0X_RangingMeasurementData_t range;
			VL53L0X_GetRangingMeasurementData(&tof, &range); // Retrieve data from device
			if (range.RangeStatus != 4) { // Data validity check
				rangeData = range; // Data OK. Copy
			}

			// Device interrupt mask must reset after reading for future interrupt event
			uint8_t n = 0;
			while (VL53L0X_ClearInterruptMask(&tof, 0) != VL53L0X_ERROR_NONE) {
				// If so many fail attempts, reset device back to boot state
				if (n == 16) {
					if (VL53L0X_ResetDevice(&tof) == VL53L0X_ERROR_NONE) {
						Sensor_Init(); // Re-init sensor
					}
				}
				n++;
			}
		}

		// Post-USB CDC Interrupt Action
		if (process.computer) {
			process.computer = 0;
			parseCommand(rxBuff); // Parse and execute designed command
			if (process.transmit) { // Should log send?
				process.transmit = 0;
				snprintf(txBuff, BUFLEN, "DIST:%u ROT0:%u RAW0:%lu"
						" ROT1:%u RAW1:%lu ROT2:%u RAW2:%lu"
						" ROT3:%u RAW3:%lu ROT4:%u RAW4:%lu\n",
						rangeData.RangeMilliMeter, grp1.rotDegree,
						htim3.Instance->CCR3, dof1.rotDegree,
						htim2.Instance->CCR1, dof2.rotDegree,
						htim2.Instance->CCR2, dof3.rotDegree,
						htim2.Instance->CCR3, dof4.rotDegree,
						htim2.Instance->CCR4);
				CDC_Transmit_FS((uint8_t*) txBuff, strlen(txBuff)); // Send log
			}
		}

		// Autoscan feature
		// Tested. Not Working. Discard
//		if (process.scan && rangeData.TimeStamp != process.timestamp) {
//			if (rangeData.RangeMilliMeter <= process.rangeTh) {
//				if (process.scanMode == 1) {
//					process.scan = 0;
//				} else {
//					if (process.capturedCCR == 0) {
//						process.capturedCCR = process.currentCCR;
//					}
//					if (!INRANGE(process.currentCCR + process.scanInc,
//							process.minScan, process.maxScan)) {
//						process.scanInc = -process.scanInc;
//					}
//					process.currentCCR += process.scanInc;
//				}
//			} else if (process.capturedCCR != 0) {
//				if (process.scanMode == 2) {
//					process.scan = 0;
//					process.currentCCR -= process.scanInc;
//				} else {
//					process.scan = 0;
//					process.currentCCR = process.capturedCCR
//							+ (process.currentCCR - process.capturedCCR) / 2;
//				}
//			} else {
//				if (!INRANGE(process.currentCCR + process.scanInc,
//						process.minScan, process.maxScan)) {
//					process.scanInc = -process.scanInc;
//				}
//				process.currentCCR += process.scanInc;
//			}
//			process.timestamp = rangeData.TimeStamp;
//			Servo_setCCR(&dof1, process.currentCCR);
//		}

		/* USER CODE END WHILE */

		/* USER CODE BEGIN 3 */
	}
	/* USER CODE END 3 */
}

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
/* USER CODE BEGIN 4 */
void Sensor_Init(void) {
	uint8_t VhvSettings;
	uint8_t PhaseCal;
	uint32_t refSpadCount;
	uint8_t isApertureSpads;
// Long Range Profile
	FixPoint1616_t signalLimit = (FixPoint1616_t) (0.25 * 65536);
	FixPoint1616_t sigmaLimit = (FixPoint1616_t) (32 * 65536);
	uint32_t timingBudget = 20000;
	//uint8_t preRangeVcselPeriod = 18;
	//uint8_t finalRangeVcselPeriod = 14;

	// Not used by library
	tof.I2cHandle = &hi2c1;
	tof.I2cDevAddr = 0x52;
	tof.comms_type = 1;
	tof.comms_speed_khz = 100;

	// Init and calibration
	VL53L0X_DataInit(&tof);
	VL53L0X_StaticInit(&tof);
	VL53L0X_PerformRefSpadManagement(&tof, &refSpadCount, &isApertureSpads);
	VL53L0X_PerformRefCalibration(&tof, &VhvSettings, &PhaseCal);

	// Parameter adjustment
	VL53L0X_SetLimitCheckEnable(&tof,
	VL53L0X_CHECKENABLE_SIGMA_FINAL_RANGE, 1);
	VL53L0X_SetLimitCheckEnable(&tof,
	VL53L0X_CHECKENABLE_SIGNAL_RATE_FINAL_RANGE, 1);
	VL53L0X_SetLimitCheckValue(&tof,
	VL53L0X_CHECKENABLE_SIGNAL_RATE_FINAL_RANGE, signalLimit);
	VL53L0X_SetLimitCheckValue(&tof,
	VL53L0X_CHECKENABLE_SIGMA_FINAL_RANGE, sigmaLimit);
	VL53L0X_SetMeasurementTimingBudgetMicroSeconds(&tof, timingBudget);
//	VL53L0X_SetVcselPulsePeriod(&tof, VL53L0X_VCSEL_PERIOD_PRE_RANGE,
//			preRangeVcselPeriod);
//	VL53L0X_SetVcselPulsePeriod(&tof, VL53L0X_VCSEL_PERIOD_FINAL_RANGE,
//			finalRangeVcselPeriod);
	VL53L0X_SetGpioConfig(&tof, 0, VL53L0X_DEVICEMODE_CONTINUOUS_RANGING,
	VL53L0X_GPIOFUNCTIONALITY_NEW_MEASURE_READY,
	VL53L0X_INTERRUPTPOLARITY_HIGH);
	VL53L0X_SetDeviceMode(&tof, VL53L0X_DEVICEMODE_CONTINUOUS_RANGING);
	VL53L0X_StartMeasurement(&tof);

	// Activate STM interrupt
	HAL_NVIC_SetPriority(EXTI9_5_IRQn, 0, 0);
	HAL_NVIC_EnableIRQ(EXTI9_5_IRQn);
}

void Actuator_Init(void) {
	// Init all servos
	Servo_Init(&dof1, &htim2, TIM2, 1, 1000, 4999);
	Servo_Init(&dof2, &htim2, TIM2, 2, 1000, 4999);
	Servo_Init(&dof3, &htim2, TIM2, 3, 1000, 4999);
	Servo_Init(&dof4, &htim2, TIM2, 4, 1000, 4999);
	Servo_Init(&grp1, &htim3, TIM3, 3, 1000, 4999);
}
/* USER CODE END 4 */
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


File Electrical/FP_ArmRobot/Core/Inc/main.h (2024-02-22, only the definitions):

#define BUFLEN 512 // UART process buffer length
#define LED_Pin GPIO_PIN_13
#define LED_GPIO_Port GPIOC
#define DOF_1_Pin GPIO_PIN_0
#define DOF_1_GPIO_Port GPIOA
#define DOF_2_Pin GPIO_PIN_1
#define DOF_2_GPIO_Port GPIOA
#define DOF_3_Pin GPIO_PIN_2
#define DOF_3_GPIO_Port GPIOA
#define DOF_4_Pin GPIO_PIN_3
#define DOF_4_GPIO_Port GPIOA
#define GRP_1_Pin GPIO_PIN_0
#define GRP_1_GPIO_Port GPIOB
#define SCL_Pin GPIO_PIN_6
#define SCL_GPIO_Port GPIOB
#define SDA_Pin GPIO_PIN_7
#define SDA_GPIO_Port GPIOB
#define VL_INT_Pin GPIO_PIN_8
#define VL_INT_GPIO_Port GPIOB
#define VL_INT_EXTI_IRQn EXTI9_5_IRQn
#define VL_SHT_Pin GPIO_PIN_9
#define VL_SHT_GPIO_Port GPIOB

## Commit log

2024-02-21 add full code
    [ARb_old.urdf]
2024-02-22 tumis bakwan
    [ARb_old.urdf]
2024-02-22 mendoan presto
    [FP_Abinara.kicad_pcb, FP_Abinara.kicad_sch, FP_Abinara.step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]
2024-02-22 semur sambel
    [0 bs 1.SLDPRT, 00total akh.SLDASM, 0atas kanan.SLDPRT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]

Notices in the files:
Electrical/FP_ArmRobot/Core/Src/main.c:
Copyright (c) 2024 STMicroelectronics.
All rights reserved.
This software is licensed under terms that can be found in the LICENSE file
